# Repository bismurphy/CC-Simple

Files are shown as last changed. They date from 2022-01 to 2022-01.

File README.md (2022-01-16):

# CC-Simple
A simple radio using the TI CC-1110 (WORK IN PROGRESS)

License & Legal Information
---------------------------

This project is directly derived from the Planet Labs OpenLST radio. My aim was to simplify it as much as possible to allow for experimentation and education.

The OpenLST is provided under a Creative Commons Attribution-ShareAlike 4.0 International License, which requires me to give them recognition, as well as to also put my work under that license. The Planet Labs repository can be found at https://github.com/OpenLST/openlst-hw

Copyright 2018 Planet Labs Inc. This work is licensed under a
Creative Commons Attribution-ShareAlike 4.0 International License.

This document may contain technology or software the export of which
is or may be restricted by the Export Administration Act and the
Export Administration Regulations (EAR), 15 C.F.R. parts
730-774. Diversion contrary to U.S. law is prohibited.

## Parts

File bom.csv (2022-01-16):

Reference | Value | Footprint | Datasheet | Manuf | ManufPN | Supplier | SupplierPN
L6 | 27n | Inductor_SMD:L_0402_1005Metric | http://search.murata.co.jp/Ceramy/image/img/P02/JELF243A-0050.pdf | Murata | LQW15AN27NJ00D | Digikey | 490-1151-1-ND
J6 | ANT | Connector_Coaxial:SMA_Molex_73251-1153_EdgeMount_Horizontal | https://www.molex.com/pdm_docs/sd/732511150_sd.pdf | Molex | 732511150 | Digikey | WM5534-ND
C45 | 220p | Capacitor_SMD:C_0402_1005Metric | https://api.kemet.com/component-edge/download/datasheet/C0402C221J2GACAUTO.pdf | Kemet | C0402C221J2GACAUTO | Digikey | 399-11552-1-ND
C25 | 220p | Capacitor_SMD:C_0402_1005Metric | https://api.kemet.com/component-edge/download/datasheet/C0402C221J2GACAUTO.pdf | Kemet | C0402C221J2GACAUTO | Digikey | 399-11552-1-ND
C24 | 3.9p | Capacitor_SMD:C_0402_1005Metric | http://search.murata.co.jp/Ceramy/image/img/A01X/G101/ENG/GJM1555C1H3R9CB01-01.pdf | Murata | GJM1555C1H3R9CB01D | Digikey | 490-3097-1-ND
L5 | 27n | Inductor_SMD:L_0402_1005Metric | http://search.murata.co.jp/Ceramy/image/img/P02/JELF243A-0050.pdf | Murata | LQW15AN27NJ00D | Digikey | 490-1151-1-ND
C21 | 220p | Capacitor_SMD:C_0402_1005Metric | https://api.kemet.com/component-edge/download/datasheet/C0402C221J2GACAUTO.pdf | Kemet | C0402C221J2GACAUTO | Digikey | 399-11552-1-ND
U1 | LM1117-3.3 | Package_TO_SOT_SMD:SOT-223-3_TabPin2 | http://www.ti.com/lit/ds/symlink/lm1117.pdf | Texas Instruments | LM1117IMP-3.3/NOPB | Digikey | LM1117IMP-3.3/NOPBCT-ND
C4 | 10u | Capacitor_SMD:C_0603_1608Metric | http://search.murata.co.jp/Ceramy/image/img/A01X/G101/ENG/GRT188C81A106ME13-01.pdf | Murata | GRT188C81A106ME13D | Digikey | 490-12283-1-ND
C13 | 10u | Capacitor_SMD:C_0603_1608Metric | http://search.murata.co.jp/Ceramy/image/img/A01X/G101/ENG/GRT188C81A106ME13-01.pdf | Murata | GRT188C81A106ME13D | Digikey | 490-12283-1-ND
C15 | 0.1u | Capacitor_SMD:C_0603_1608Metric | http://datasheets.avx.com/AutoMLCC.pdf | AVX | 0603YC104K4T4A | Digikey | 478-9382-1-ND
J1 | 5VDC | Connector_PinHeader_2.54mm:PinHeader_1x02_P2.54mm_Vertical
D3 | STPS340U | Diode_SMD:D_SMB | http://www.st.com/content/ccc/resource/technical/document/datasheet/bb/db/21/0c/04/d9/41/a5/CD00000844.pdf/files/CD00000844.pdf/jcr:content/translations/en.CD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 | STMicroelectronics | STPS340U | Digikey | 497-2465-1-ND
L2 | Z=500 @ 100M | Inductor_SMD:L_1206_3216Metric | https://assets.lairdtech.com/home/brandworld/files/MI1206L501R-10.pdf | Laird | MI1206L501R-10 | Digikey | 240-2407-1-ND
C14 | 100u | Capacitor_SMD:C_2312_6032Metric | https://datasheets.kyocera-avx.com/TAJ.pdf | Kyocera | TAJC107K010RNJ | Digikey | 478-1704-1-ND
U3 | LT1086-3.6 | Package_TO_SOT_SMD:TO-263-3_TabPin2 | http://www.linear.com/docs/1722 | Linear | LT1086CM-3.6#PBF | Digikey | LT1086CM-3.6#PBF-ND
C46 | 1u | Capacitor_SMD:C_0603_1608Metric | http://www.samsungsem.com/kr/support/product-search/mlcc/CL10B105MO8NNWC.jsp | Samsung | CL10B105MO8NNWC | Digikey | 1276-6524-6-ND
C44 | 1u | Capacitor_SMD:C_0603_1608Metric | http://www.samsungsem.com/kr/support/product-search/mlcc/CL10B105MO8NNWC.jsp | Samsung | CL10B105MO8NNWC | Digikey | 1276-6524-6-ND
U6 | PE4259 | Package_TO_SOT_SMD:SOT-363_SC-70-6 | http://www.psemi.com/pdf/datasheets/pe4259ds.pdf | pSemi | 4259-63 | Digikey | 1046-1011-1-ND
C38 | 220p | Capacitor_SMD:C_0402_1005Metric | https://api.kemet.com/component-edge/download/datasheet/C0402C221J2GACAUTO.pdf | Kemet | C0402C221J2GACAUTO | Digikey | 399-11552-1-ND
C39 | 220p | Capacitor_SMD:C_0402_1005Metric | https://api.kemet.com/component-edge/download/datasheet/C0402C221J2GACAUTO.pdf | Kemet | C0402C221J2GACAUTO | Digikey | 399-11552-1-ND
C26 | 0.1u | Capacitor_SMD:C_0603_1608Metric | http://datasheets.avx.com/AutoMLCC.pdf | AVX | 0603YC104K4T4A | Digikey | 478-9382-1-ND
U2 | CC1110 | openlst:TI_CC_QFN36 | http://www.ti.com/lit/ds/symlink/cc1110-cc1111.pdf | Texas Instruments | CC1110F32RHHR | Digikey | 296-38560-1-ND
U5 | TLV803S | Package_TO_SOT_SMD:SOT-23 | http://www.ti.com/lit/ds/symlink/tlv803.pdf | Texas Instruments | TLV803SDBZR | Digikey | 296-29196-1-ND
R18 | 1K | Resistor_SMD:R_0603_1608Metric | http://www.yageo.com/documents/recent/PYu-RC_Group_51_RoHS_L_9.pdf | Yageo | RC0603JR-071KL | Digikey | 311-1.0KGRCT-ND
C22 | 1n | Capacitor_SMD:C_0603_1608Metric | https://www.murata.com/~/media/webrenewal/support/library/catalog/products/capacitor/mlcc/c03e.ashx | Murata | GCM188R71E102KA37D | Digikey | 490-8016-1-ND
R16 | 56K | Resistor_SMD:R_0603_1608Metric | https://www.seielect.com/Catalog/SEI-RMCF_RMCP.pdf | Stackpole | RMCF0603FT56K0 | Digikey | RMCF0603FT56K0CT-ND
C19 | 1n | Capacitor_SMD:C_0603_1608Metric | https://www.murata.com/~/media/webrenewal/support/library/catalog/products/capacitor/mlcc/c03e.ashx | Murata | GCM188R71E102KA37D | Digikey | 490-8016-1-ND
J2 | CC Prog/Debug | Connector_PinHeader_1.27mm:PinHeader_2x05_P1.27mm_Vertical_SMD | http://suddendocs.samtec.com/prints/ftsh-1xx-xx-xxx-dv-xxx-xxx-mkt.pdf | Samtec | FTSH-105-01-L-DV-K-P | Digikey | SAM9076-ND
R5 | 100 | Resistor_SMD:R_0603_1608Metric | http://www.yageo.com/NewPortal/yageodocoutput?fileName=/pdf/R-Chip/PYu-AC_51_RoHS_L_6.pdf | Yageo | AC0603FR-07100RL | Digikey | YAG3561CT-ND
R6 | 100 | Resistor_SMD:R_0603_1608Metric | http://www.yageo.com/NewPortal/yageodocoutput?fileName=/pdf/R-Chip/PYu-AC_51_RoHS_L_6.pdf | Yageo | AC0603FR-07100RL | Digikey | YAG3561CT-ND
R7 | 100 | Resistor_SMD:R_0603_1608Metric | http://www.yageo.com/NewPortal/yageodocoutput?fileName=/pdf/R-Chip/PYu-AC_51_RoHS_L_6.pdf | Yageo | AC0603FR-07100RL | Digikey | YAG3561CT-ND
R8 | 100 | Resistor_SMD:R_0603_1608Metric | http://www.yageo.com/NewPortal/yageodocoutput?fileName=/pdf/R-Chip/PYu-AC_51_RoHS_L_6.pdf | Yageo | AC0603FR-07100RL | Digikey | YAG3561CT-ND
R9 | 100 | Resistor_SMD:R_0603_1608Metric | http://www.yageo.com/NewPortal/yageodocoutput?fileName=/pdf/R-Chip/PYu-AC_51_RoHS_L_6.pdf | Yageo | AC0603FR-07100RL | Digikey | YAG3561CT-ND
R10 | 100 | Resistor_SMD:R_0603_1608Metric | http://www.yageo.com/NewPortal/yageodocoutput?fileName=/pdf/R-Chip/PYu-AC_51_RoHS_L_6.pdf | Yageo | AC0603FR-07100RL | Digikey | YAG3561CT-ND
R11 | 100 | Resistor_SMD:R_0603_1608Metric | http://www.yageo.com/NewPortal/yageodocoutput?fileName=/pdf/R-Chip/PYu-AC_51_RoHS_L_6.pdf | Yageo | AC0603FR-07100RL | Digikey | YAG3561CT-ND
R12 | 100 | Resistor_SMD:R_0603_1608Metric | http://www.yageo.com/NewPortal/yageodocoutput?fileName=/pdf/R-Chip/PYu-AC_51_RoHS_L_6.pdf | Yageo | AC0603FR-07100RL | Digikey | YAG3561CT-ND
C31 | 0.1u | Capacitor_SMD:C_0603_1608Metric | http://datasheets.avx.com/AutoMLCC.pdf | AVX | 0603YC104K4T4A | Digikey | 478-9382-1-ND
R28 | 1K | Resistor_SMD:R_0603_1608Metric | http://www.yageo.com/documents/recent/PYu-RC_Group_51_RoHS_L_9.pdf | Yageo | RC0603JR-071KL | Digikey | 311-1.0KGRCT-ND
R26 | 1K | Resistor_SMD:R_0603_1608Metric | http://www.yageo.com/documents/recent/PYu-RC_Group_51_RoHS_L_9.pdf | Yageo | RC0603JR-071KL | Digikey | 311-1.0KGRCT-ND
R1 | 1K | Resistor_SMD:R_0603_1608Metric | http://www.yageo.com/documents/recent/PYu-RC_Group_51_RoHS_L_9.pdf | Yageo | RC0603JR-071KL | Digikey | 311-1.0KGRCT-ND
R2 | 1K | Resistor_SMD:R_0603_1608Metric | http://www.yageo.com/documents/recent/PYu-RC_Group_51_RoHS_L_9.pdf | Yageo | RC0603JR-071KL | Digikey | 311-1.0KGRCT-ND
U4 | FOX924 27MHz | Oscillator:Oscillator_SMD_Fordahl_DFAS15-4Pin_5.0x3.2mm | http://www.foxonline.com/pdfs/fox924.pdf | Fox Electronics | FT5HNBPK27.0-T1 | Digikey | 631-1075-1-ND
R17 | 100 | Resistor_SMD:R_0603_1608Metric | http://www.yageo.com/NewPortal/yageodocoutput?fileName=/pdf/R-Chip/PYu-AC_51_RoHS_L_6.pdf | Yageo | AC0603FR-07100RL | Digikey | YAG3561CT-ND
C23 | 3.9p | Capacitor_SMD:C_0402_1005Metric | http://search.murata.co.jp/Ceramy/image/img/A01X/G101/ENG/GJM1555C1H3R9CB01-01.pdf | Murata | GJM1555C1H3R9CB01D | Digikey | 490-3097-1-ND
C27 | 0.1u | Capacitor_SMD:C_0603_1608Metric | http://datasheets.avx.com/AutoMLCC.pdf | AVX | 0603YC104K4T4A | Digikey | 478-9382-1-ND
R15 | DNI | Resistor_SMD:R_0603_1608Metric
D1 | LED | LED_SMD:LED_0603_1608Metric | http://katalog.we-online.de/led/datasheet/150060VS75000.pdf | Wurth | 150060VS75000 | Digikey | 732-4980-1-ND
R3 | 1K | Resistor_SMD:R_0603_1608Metric | http://www.yageo.com/documents/recent/PYu-RC_Group_51_RoHS_L_9.pdf | Yageo | RC0603JR-071KL | Digikey | 311-1.0KGRCT-ND
D2 | LED | LED_SMD:LED_0603_1608Metric | http://katalog.we-online.de/led/datasheet/150060SS75000.pdf | Wurth | 150060SS75000 | Digikey | 732-4979-1-ND
R4 | 1K | Resistor_SMD:R_0603_1608Metric | http://www.yageo.com/documents/recent/PYu-RC_Group_51_RoHS_L_9.pdf | Yageo | RC0603JR-071KL | Digikey | 311-1.0KGRCT-ND
J3 | UART0 | Connector_PinHeader_2.54mm:PinHeader_1x06_P2.54mm_Vertical | http://katalog.we-online.de/em/datasheet/6130xx11121.pdf | Wurth | 61300611121 | Digikey | 732-5319-ND
R19 | DNI | Resistor_SMD:R_0603_1608Metric
J4 | UART1 | Connector_PinHeader_2.54mm:PinHeader_1x06_P2.54mm_Vertical | http://katalog.we-online.de/em/datasheet/6130xx11121.pdf | Wurth | 61300611121 | Digikey | 732-5319-ND
R20 | DNI | Resistor_SMD:R_0603_1608Metric
C1 | 0.1u | Capacitor_SMD:C_0603_1608Metric | http://datasheets.avx.com/AutoMLCC.pdf | AVX | 0603YC104K4T4A | Digikey | 478-9382-1-ND
C10 | 0.1u | Capacitor_SMD:C_0603_1608Metric | http://datasheets.avx.com/AutoMLCC.pdf | AVX | 0603YC104K4T4A | Digikey | 478-9382-1-ND
C2 | 220p | Capacitor_SMD:C_0402_1005Metric | https://api.kemet.com/component-edge/download/datasheet/C0402C221J2GACAUTO.pdf | Kemet | C0402C221J2GACAUTO | Digikey | 399-11552-1-ND
C7 | 220p | Capacitor_SMD:C_0402_1005Metric | https://api.kemet.com/component-edge/download/datasheet/C0402C221J2GACAUTO.pdf | Kemet | C0402C221J2GACAUTO | Digikey | 399-11552-1-ND
C5 | 0.1u | Capacitor_SMD:C_0603_1608Metric | http://datasheets.avx.com/AutoMLCC.pdf | AVX | 0603YC104K4T4A | Digikey | 478-9382-1-ND
C3 | 0.1u | Capacitor_SMD:C_0603_1608Metric | http://datasheets.avx.com/AutoMLCC.pdf | AVX | 0603YC104K4T4A | Digikey | 478-9382-1-ND
C9 | 1u | Capacitor_SMD:C_0603_1608Metric | http://www.samsungsem.com/kr/support/product-search/mlcc/CL10B105MO8NNWC.jsp | Samsung | CL10B105MO8NNWC | Digikey | 1276-6524-6-ND
R21 | 33K | Resistor_SMD:R_0603_1608Metric | http://www.yageo.com/NewPortal/yageodocoutput?fileName=/pdf/R-Chip/PYu-AC_51_RoHS_L_6.pdf | Yageo | AC0603FR-0733KL | Digikey | YAG3598CT-ND
R22 | 10K | Resistor_SMD:R_0603_1608Metric | http://www.yageo.com/documents/recent/PYu-RC_Group_51_RoHS_L_9.pdf | Yageo | RC0603JR-0710KL | Digikey | 311-10KGRCT-ND
R23 | 33K | Resistor_SMD:R_0603_1608Metric | http://www.yageo.com/NewPortal/yageodocoutput?fileName=/pdf/R-Chip/PYu-AC_51_RoHS_L_6.pdf | Yageo | AC0603FR-0733KL | Digikey | YAG3598CT-ND
R24 | 10K | Resistor_SMD:R_0603_1608Metric | http://www.yageo.com/documents/recent/PYu-RC_Group_51_RoHS_L_9.pdf | Yageo | RC0603JR-0710KL | Digikey | 311-10KGRCT-ND
R36 | 5K6 | Resistor_SMD:R_0603_1608Metric | https://www.seielect.com/Catalog/SEI-RMCF_RMCP.pdf | Stackpole | RMCF0603FT5K60 | Digikey | RMCF0603FT5K60CT-ND
R37 | 3K3 | Resistor_SMD:R_0603_1608Metric | https://www.seielect.com/Catalog/SEI-RMCF_RMCP.pdf | Stackpole | RMCF0603FT3K30 | Digikey | RMCF0603FT3K30CT-ND
C47 | 1u | Capacitor_SMD:C_0603_1608Metric | http://www.samsungsem.com/kr/support/product-search/mlcc/CL10B105MO8NNWC.jsp | Samsung | CL10B105MO8NNWC | Digikey | 1276-6524-6-ND
C18 | 10u | Capacitor_SMD:C_0603_1608Metric | http://search.murata.co.jp/Ceramy/image/img/A01X/G101/ENG/GRT188C81A106ME13-01.pdf | Murata | GRT188C81A106ME13D | Digikey | 490-12283-1-ND
C20 | 10u | Capacitor_SMD:C_0603_1608Metric | http://search.murata.co.jp/Ceramy/image/img/A01X/G101/ENG/GRT188C81A106ME13-01.pdf | Murata | GRT188C81A106ME13D | Digikey | 490-12283-1-ND
L8 | Z=1k @ 100M | Inductor_SMD:L_0603_1608Metric | http://katalog.we-online.de/pbs/datasheet/74279266.pdf | Wurth | 74279266 | Digikey | 732-4484-1-ND
L3 | Z=1k @ 100M | Inductor_SMD:L_0603_1608Metric | http://katalog.we-online.de/pbs/datasheet/74279266.pdf | Wurth | 74279266 | Digikey | 732-4484-1-ND
J5 | Control Outputs | Connector_PinHeader_2.54mm:PinHeader_1x03_P2.54mm_Vertical
R14 | 100 | Resistor_SMD:R_0603_1608Metric | http://www.yageo.com/NewPortal/yageodocoutput?fileName=/pdf/R-Chip/PYu-AC_51_RoHS_L_6.pdf | Yageo | AC0603FR-07100RL | Digikey | YAG3561CT-ND
R13 | 100 | Resistor_SMD:R_0603_1608Metric | http://www.yageo.com/NewPortal/yageodocoutput?fileName=/pdf/R-Chip/PYu-AC_51_RoHS_L_6.pdf | Yageo | AC0603FR-07100RL | Digikey | YAG3561CT-ND
U8 | STA1120A | openlst:SAW-8_3.8mm |  | Sawtron | STA1120A
R25 | DNI | Resistor_SMD:R_0603_1608Metric
R27 | 33K | Resistor_SMD:R_0603_1608Metric | http://www.yageo.com/NewPortal/yageodocoutput?fileName=/pdf/R-Chip/PYu-AC_51_RoHS_L_6.pdf | Yageo | AC0603FR-0733KL | Digikey | YAG3598CT-ND
C6 | 0.1u | Capacitor_SMD:C_0603_1608Metric | http://datasheets.avx.com/AutoMLCC.pdf | AVX | 0603YC104K4T4A | Digikey | 478-9382-1-ND
C8 | 0.1u | Capacitor_SMD:C_0603_1608Metric | http://datasheets.avx.com/AutoMLCC.pdf | AVX | 0603YC104K4T4A | Digikey | 478-9382-1-ND
U9 | RFFM6403 | openlst:Qorvo_LGA_28_ThermalVias | https://www.qorvo.com/products/d/da000805 | Qorvo | RFFM6403SB
MK1 | M3_Hole | MountingHole:MountingHole_3.2mm_M3_Pad_Via
R29 | DNI | Resistor_SMD:R_0603_1608Metric
R31 | DNI | Resistor_SMD:R_0603_1608Metric
MK3 | M3_Hole | MountingHole:MountingHole_3.2mm_M3_Pad_Via
MK2 | M3_Hole | MountingHole:MountingHole_3.2mm_M3_Pad_Via
R30 | DNI | Resistor_SMD:R_0603_1608Metric
R32 | DNI | Resistor_SMD:R_0603_1608Metric
MK4 | M3_Hole | MountingHole:MountingHole_3.2mm_M3_Pad_Via

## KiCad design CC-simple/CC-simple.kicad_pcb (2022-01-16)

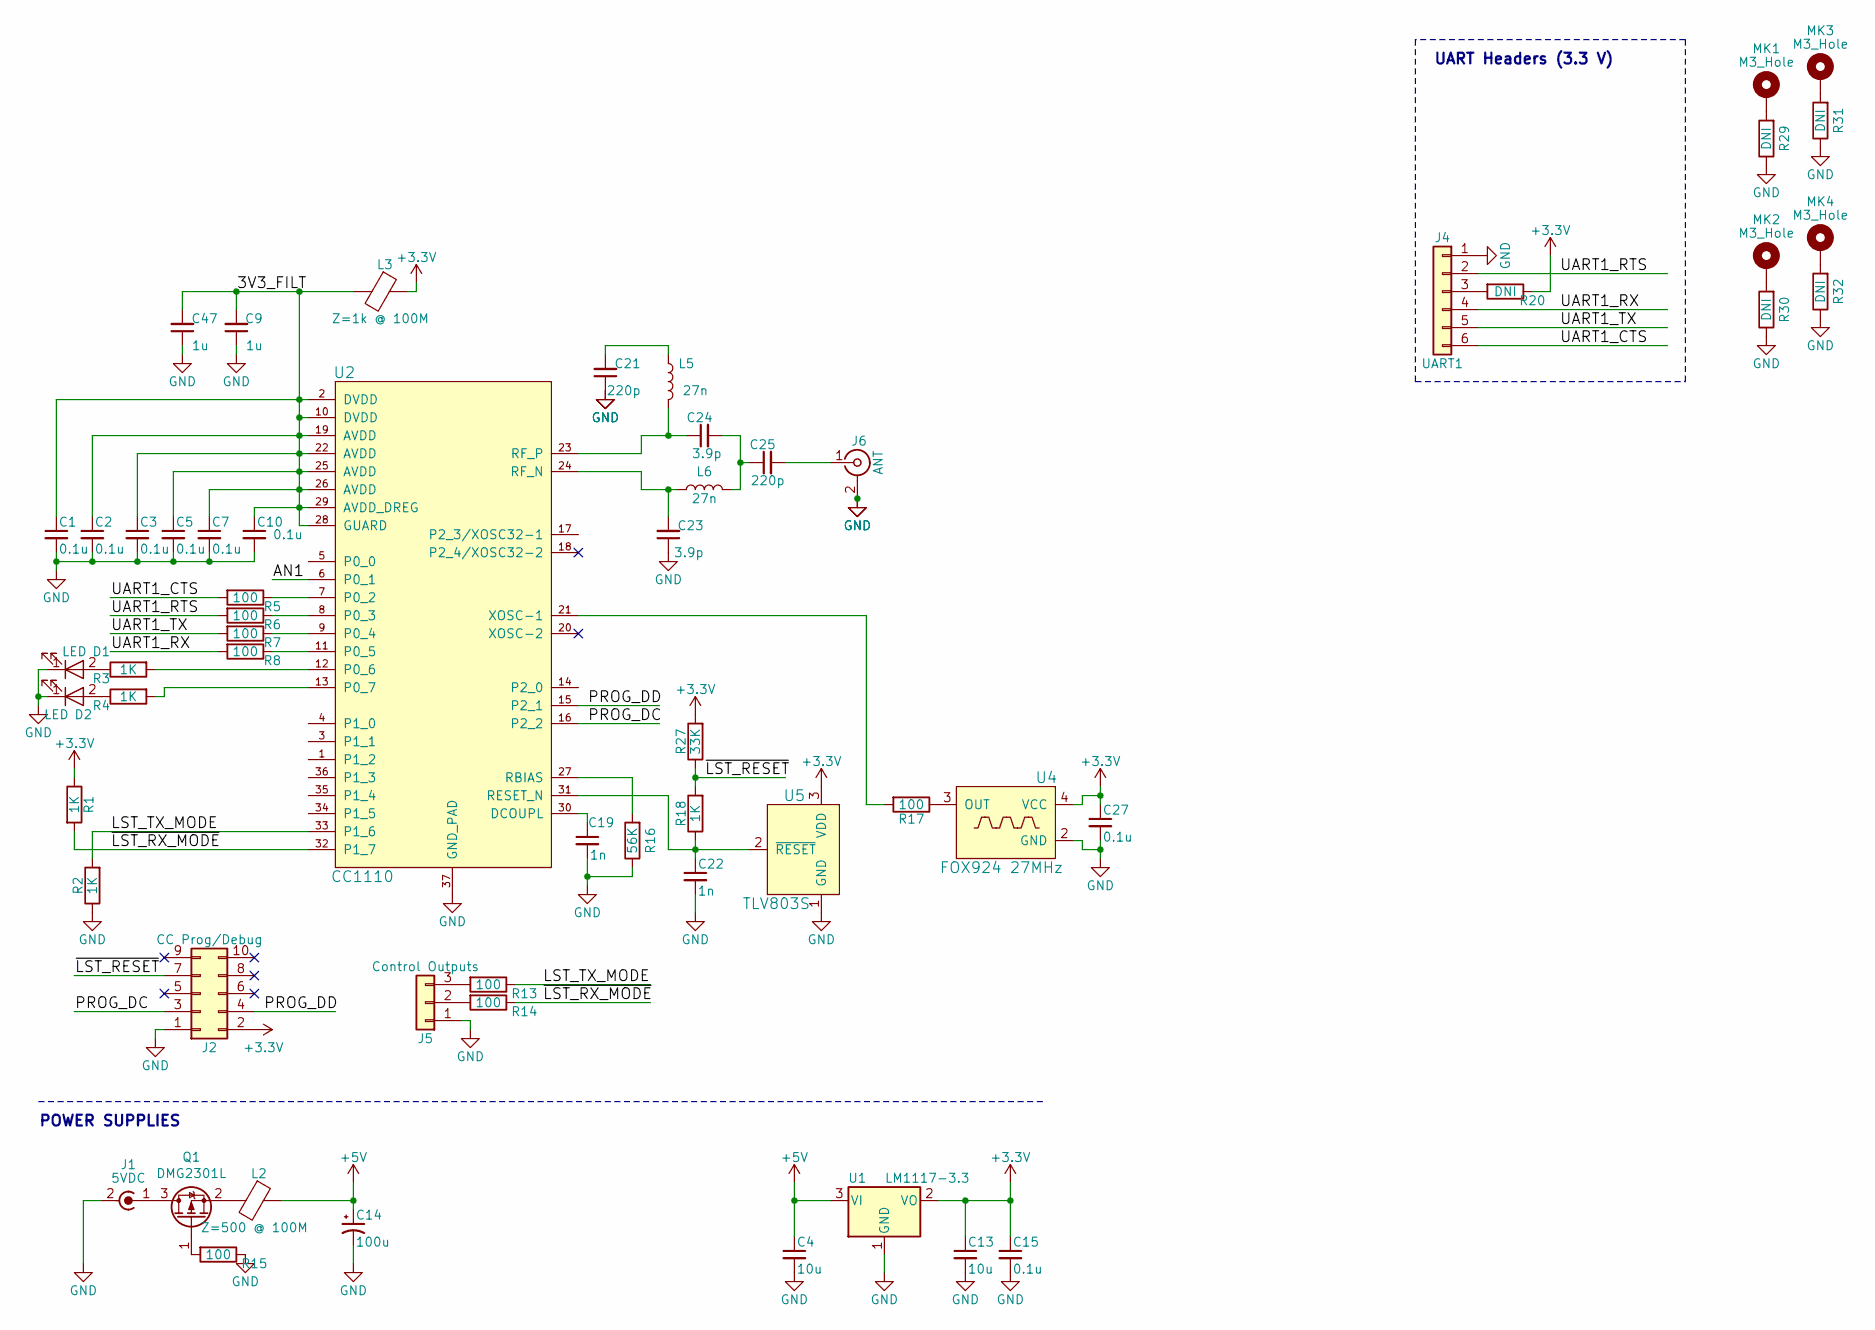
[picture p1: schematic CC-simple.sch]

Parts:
C1, C3, C5, C10, C15, C27: 0.1u; C_0603_1608Metric; ManufPN 0603YC104K4T4A
C2, C7: 0.1u; C_0603_1608Metric; ManufPN C0402C221J2GACAUTO
C4, C13: 10u; C_0603_1608Metric; ManufPN GRT188C81A106ME13D
C9, C47: 1u; C_0603_1608Metric; ManufPN CL10B105MO8NNWC
C14: 100u; CP_EIA-3528-15_AVX-H; ManufPN TPSB107M010R0400
C19, C22: 1n; C_0603_1608Metric; ManufPN GCM188R71E102KA37D
C21, C25: 220p; C_0402_1005Metric; ManufPN C0402C221J2GACAUTO
C23, C24: 3.9p; C_0402_1005Metric; ManufPN GJM1555C1H3R9CB01D
D1: LED; LED_0603_1608Metric; ManufPN 150060VS75000
D2: LED; LED_0603_1608Metric; ManufPN 150060SS75000
J1: 5VDC; PinHeader_1x02_P2.54mm_Vertical
J2: CC Prog/Debug; PinHeader_2x05_P1.27mm_Vertical_SMD; ManufPN FTSH-105-01-L-DV-K-P
J4: UART1; PinHeader_1x06_P2.54mm_Vertical; ManufPN 61300611121
J5: Control Outputs; PinHeader_1x03_P2.54mm_Vertical
J6: ANT; SMA_Molex_73251-1153_EdgeMount_Horizontal; ManufPN 732511150
L2: Z=500 @ 100M; L_1206_3216Metric; ManufPN MI1206L501R-10
L3: Z=1k @ 100M; L_0603_1608Metric; ManufPN 74279266
L5, L6: 27n; L_0402_1005Metric; ManufPN LQW15AN27NJ00D
MK1, MK2, MK3, MK4: M3_Hole; MountingHole_3.2mm_M3_Pad_Via
Q1: DMG2301L; SOT-23
R1, R2, R3, R4, R18: 1K; R_0603_1608Metric; ManufPN RC0603JR-071KL
R5, R6, R7, R8, R13, R14, R15, R17: 100; R_0603_1608Metric; ManufPN AC0603FR-07100RL
R16: 56K; R_0603_1608Metric; ManufPN RMCF0603FT56K0
R20, R29, R30, R31, R32: DNI; R_0603_1608Metric
R27: 33K; R_0603_1608Metric; ManufPN AC0603FR-0733KL
U1: LM1117-3.3; SOT-223-3_TabPin2; ManufPN LM1117IMP-3.3/NOPB
U2: CC1110; TI_CC_QFN36; ManufPN CC1110F32RHHR
U4: FOX924 27MHz; Oscillator_SMD_Fordahl_DFAS15-4Pin_5.0x3.2mm; ManufPN FT5HNBPK27.0-T1
U5: TLV803S; SOT-23; ManufPN TLV803SDBZR

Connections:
+3V3: C13.1, C15.1, C27.1, J2.2, L3.1, R1.1, R20.1, R27.2, U1.2 (VO), U4.4 (VCC), U5.3 (VDD)
+5V: C4.1, C14.1, L2.1, U1.3 (VI)
/3V3_FILT: C1.1, C2.1, C3.1, C5.1, C7.1, C9.2, C10.1, C47.2, L3.2, U2.2 (DVDD), U2.10 (DVDD), U2.19 (AVDD), U2.22 (AVDD), U2.25 (AVDD), U2.26 (AVDD), U2.28 (GUARD), U2.29 (AVDD_DREG)
/LST_TX_MODE: R2.2, R13.1, U2.33 (P1_6)
/PROG_DC: J2.3, U2.16 (P2_2)
/PROG_DD: J2.4, U2.15 (P2_1)
/UART1_CTS: J4.6, R5.2
/UART1_RTS: J4.2, R6.2
/UART1_RX: J4.4, R8.2
/UART1_TX: J4.5, R7.2
/~LST_RESET: J2.7, R18.2, R27.1
/~LST_RX_MODE: R1.2, R14.1, U2.32 (P1_7)
GND: C1.2, C2.2, C3.2, C4.2, C5.2, C7.2, C9.1, C10.2, C13.2, C14.2, C15.2, C19.2, C21.1, C22.2, C23.1, C27.2, C47.1, D1.1 (K), D2.1 (K), J1.2 (Ext), J2.1, J4.1, J5.1, J6.2 (Ext), R2.1, R15.1, R16.1, R29.1, R30.1, R31.1, R32.1, U1.1 (GND), U2.37 (GND_PAD), U4.2 (GND), U5.1 (GND)
unnamed: C19.1, U2.30 (DCOUPL)
unnamed: C21.2, L5.1
unnamed: C22.1, R18.1, U2.31 (RESET_N), U5.2 (~RESET~)
unnamed: C23.2, L6.1, U2.24 (RF_N)
unnamed: C24.1, L5.2, U2.23 (RF_P)
unnamed: C24.2, C25.1, L6.2
unnamed: C25.2, J6.1 (In)
unnamed: D1.2 (A), R3.1
unnamed: D2.2 (A), R4.1
unnamed: J1.1 (In), Q1.3 (D)
unnamed: J4.3, R20.2
unnamed: J5.2, R14.2
unnamed: J5.3, R13.2
unnamed: L2.2, Q1.2 (S)
unnamed: MK1.1, R29.2
unnamed: MK2.1, R30.2
unnamed: MK3.1, R31.2
unnamed: MK4.1, R32.2
unnamed: Q1.1 (G), R15.2
unnamed: R3.2, U2.12 (P0_6)
unnamed: R4.2, U2.13 (P0_7)
unnamed: R5.1, U2.7 (P0_2)
unnamed: R6.1, U2.8 (P0_3)
unnamed: R7.1, U2.9 (P0_4)
unnamed: R8.1, U2.11 (P0_5)
unnamed: R16.2, U2.27 (RBIAS)
unnamed: R17.1, U4.3 (OUT)
unnamed: R17.2, U2.21 (XOSC-1)

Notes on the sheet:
POWER SUPPLIES
UART Headers (3.3 V)

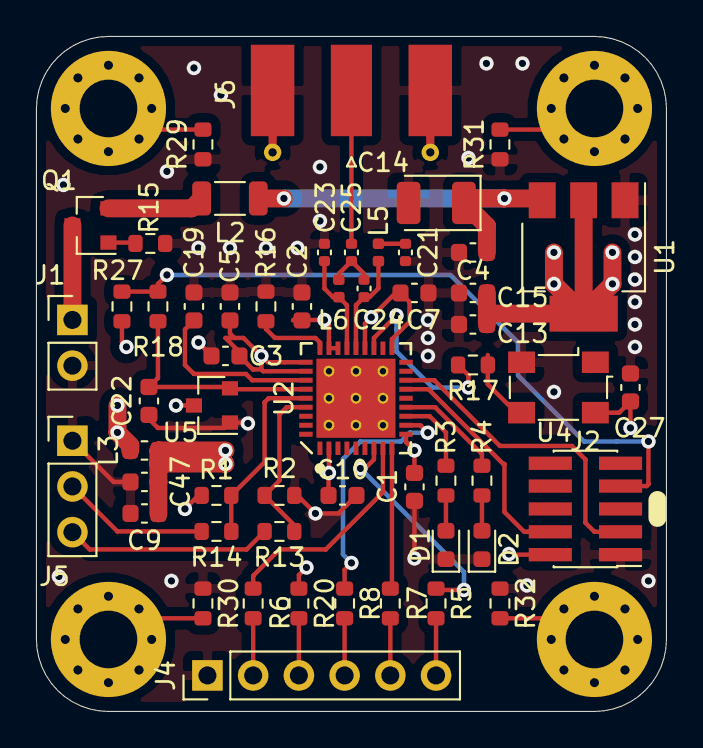
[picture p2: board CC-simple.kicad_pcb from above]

Board: 4 copper layers, 35.0 x 37.5 mm, 59 parts (0 on the bottom side), 41 nets.
